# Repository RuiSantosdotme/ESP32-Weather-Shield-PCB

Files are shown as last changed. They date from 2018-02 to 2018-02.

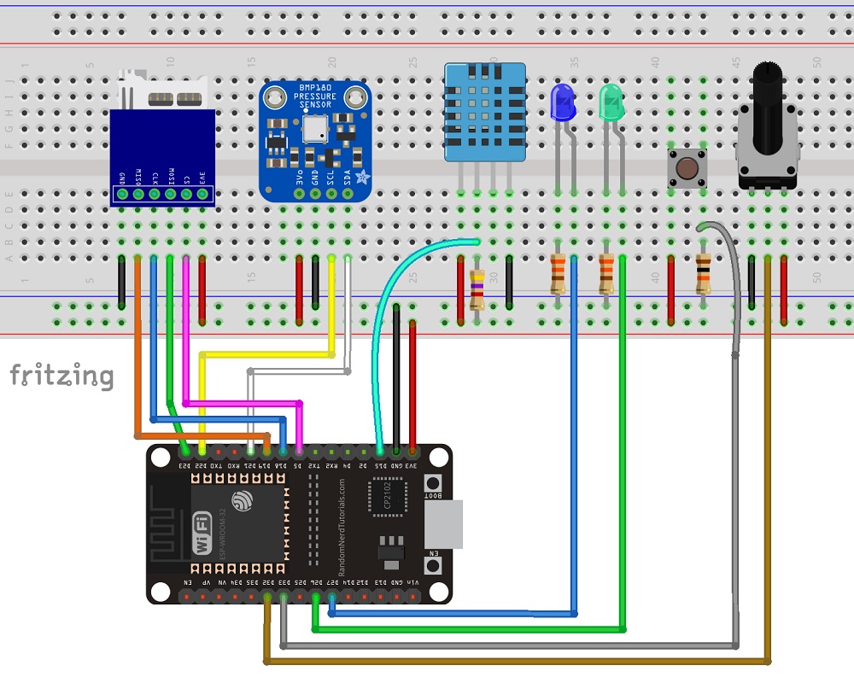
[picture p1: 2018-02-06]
Images/ESP32-shield-breadboard.jpg

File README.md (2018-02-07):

# Build an All-in-One ESP32 Weather Station Shield

In this project I’ll show you how you can build an all-in-one ESP32 weather station shield and display the sensor readings on a web server. The web server displays data from all the sensors and automatically updates the readings every ten seconds, without the need to refresh the web page.

You can watch the video tutorial and demonstration here: https://youtu.be/m5cS21AAhZo

For the complete step-by-step instructions, visit: https://randomnerdtutorials.com/build-an-all-in-one-esp32-weather-station-shield/

How to browse the GitHub repository:
- [Web server code (for Arduino IDE)](https://raw.githubusercontent.com/RuiSantosdotme/ESP32-Weather-Shield-PCB/master/Code/ESP32_Weather_Station_Shield/ESP32_Weather_Station_Shield.ino)
- [HTML page](https://raw.githubusercontent.com/RuiSantosdotme/ESP32-Weather-Shield-PCB/master/Code/index.html)
- [Schematic diagram](https://github.com/RuiSantosdotme/ESP32-Weather-Shield-PCB/tree/master/Images)
- [Gerber files](https://github.com/RuiSantosdotme/ESP32-Weather-Shield-PCB/raw/master/KiCad_PCB_ESP32_Shield/GERBERS/ESP32_Shield_Gerbers.zip)
- [KiCad project to edit the PCB](https://github.com/RuiSantosdotme/ESP32-Weather-Shield-PCB/tree/master/KiCad_PCB_ESP32_Shield)
- [Click here to download all the files](https://github.com/RuiSantosdotme/ESP32-Weather-Shield-PCB/archive/master.zip)

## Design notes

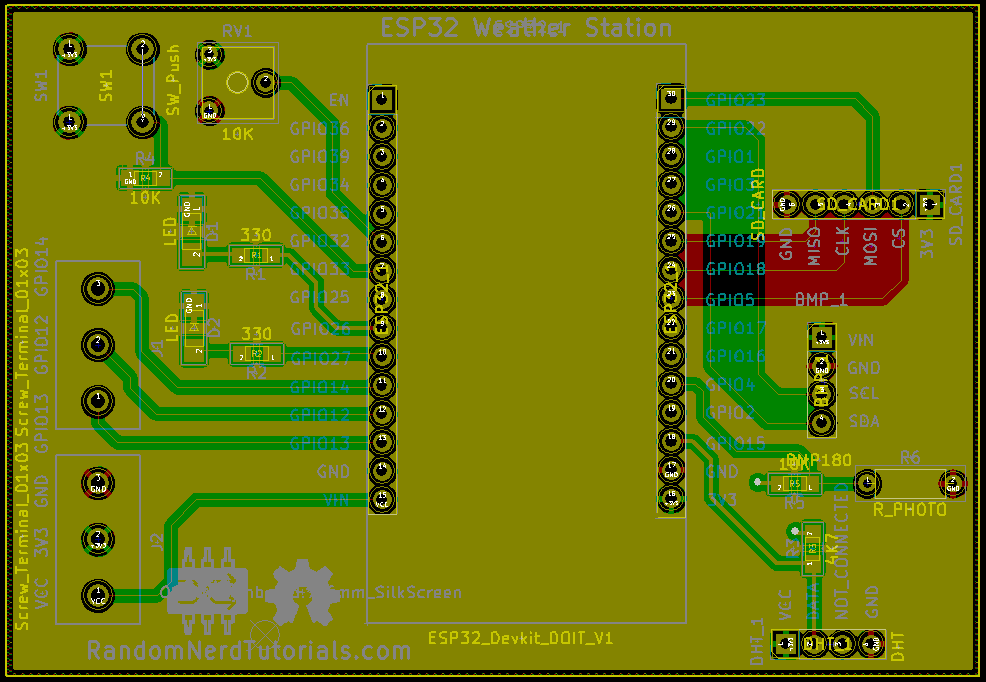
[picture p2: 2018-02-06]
Images/KiCad-PCB-top-view.png

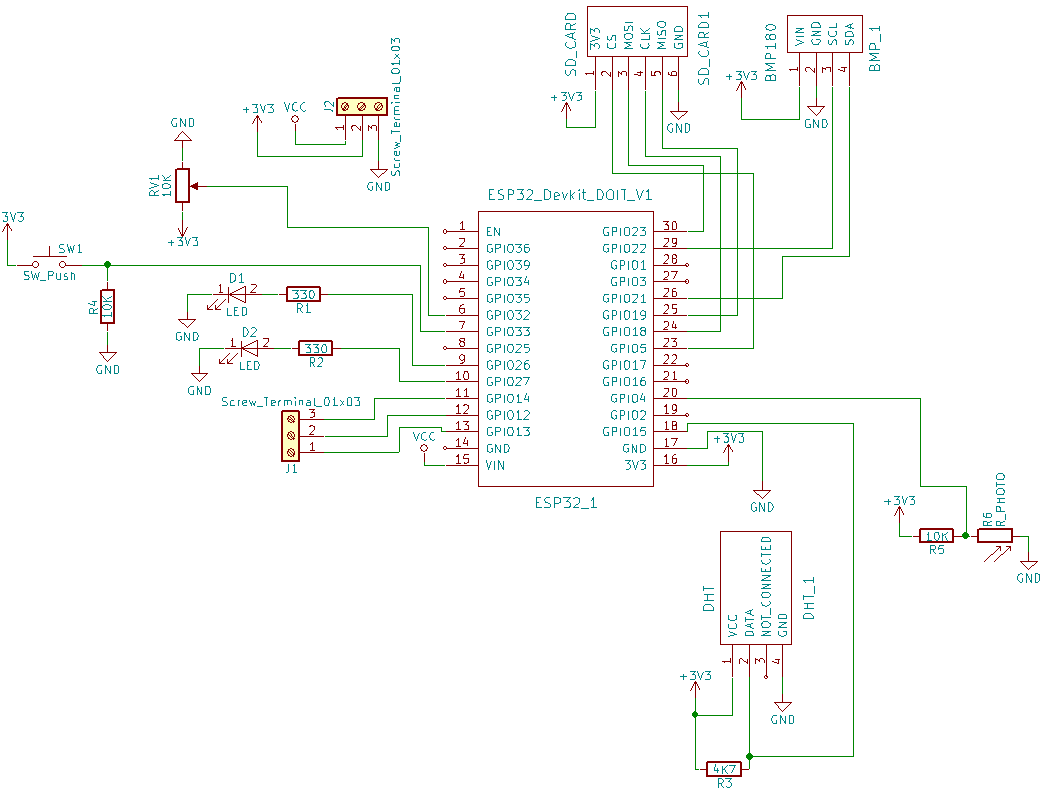
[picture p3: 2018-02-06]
Images/KiCad-circuit.png

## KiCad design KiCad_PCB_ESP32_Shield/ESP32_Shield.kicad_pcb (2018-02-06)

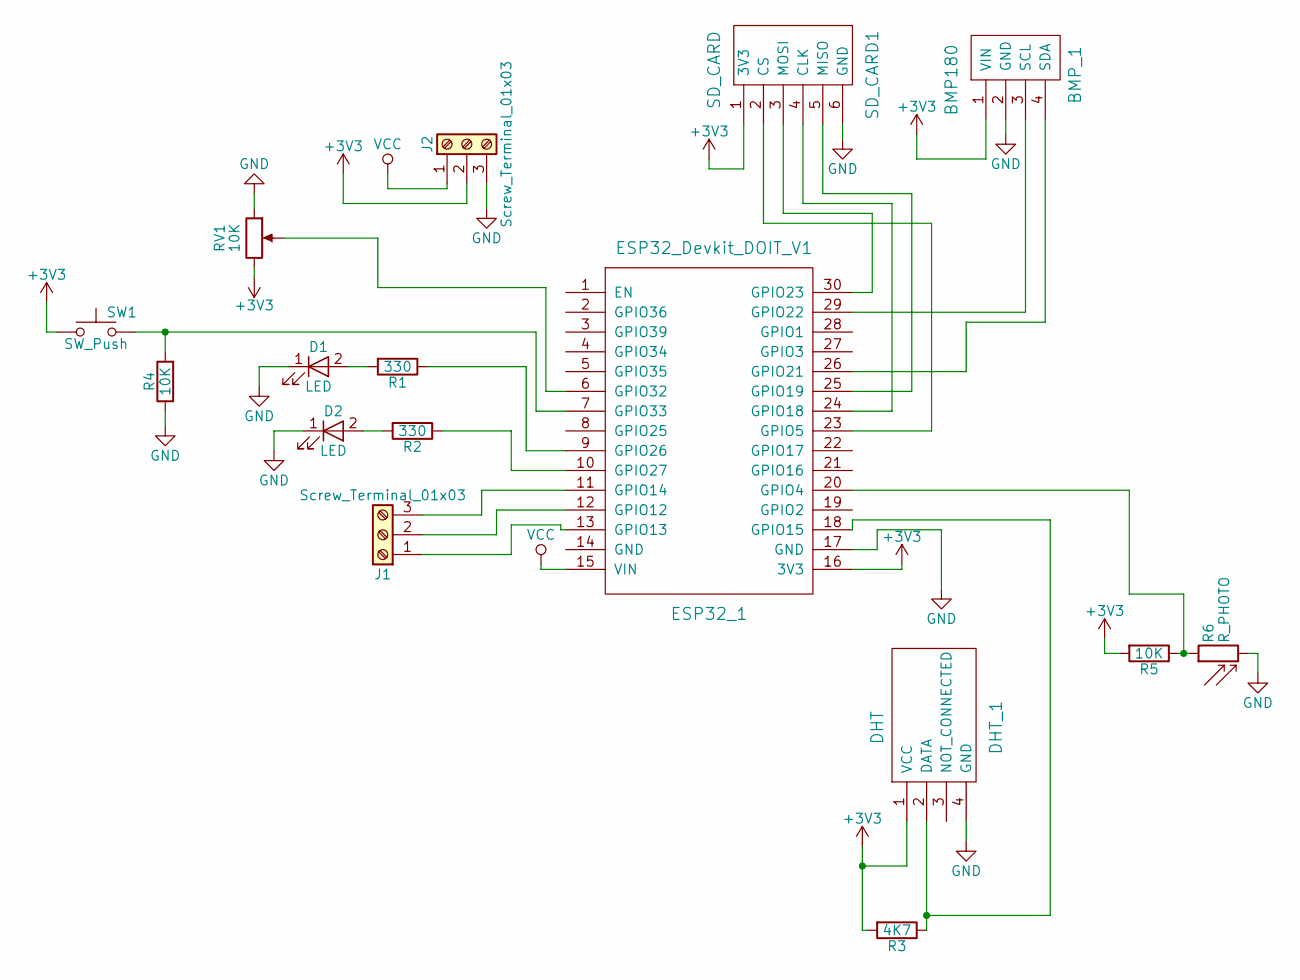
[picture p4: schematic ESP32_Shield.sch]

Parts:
BMP_1: BMP180
D1, D2: LED; LED_1206_HandSoldering
DHT_1: DHT
ESP32_1: ESP32_Devkit_DOIT_V1
J1: Screw_Terminal_01x03; TerminalBlock_5mm_Pins
J2: Screw_Terminal_01x03; TerminalBlock_5mm
R1, R2: 330; R_0805_HandSoldering
R3: 4K7; R_0805_HandSoldering
R4, R5: 10K; R_0805_HandSoldering
R6: R_PHOTO; R_Axial_DIN0207_L6.3mm_D2.5mm_P7.62mm_Horizontal
RV1: 10K; Potentiometer_Trimmer_ACP_CA6v_Horizontal
SD_CARD1: SD_CARD
SW1: SW_Push; SW_PUSH_6mmx6mm

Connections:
+3V3: BMP_1.1 (VIN), DHT_1.1 (VCC), ESP32_1.16 (3V3), J2.2, R3.2, R5.2, RV1.3, SD_CARD1.1 (3V3), SW1.1
GND: BMP_1.2 (GND), D1.1 (K), D2.1 (K), DHT_1.4 (GND), ESP32_1.17 (GND), J2.3, R4.1, R6.2, RV1.1, SD_CARD1.6 (GND)
unnamed: BMP_1.3 (SCL), ESP32_1.29 (GPIO22)
unnamed: BMP_1.4 (SDA), ESP32_1.26 (GPIO21)
unnamed: D1.2 (A), R1.2
unnamed: D2.2 (A), R2.2
unnamed: DHT_1.2 (DATA), ESP32_1.18 (GPIO15), R3.1
unnamed: ESP32_1.6 (GPIO32), RV1.2
unnamed: ESP32_1.7 (GPIO33), R4.2, SW1.2
unnamed: ESP32_1.9 (GPIO26), R1.1
unnamed: ESP32_1.10 (GPIO27), R2.1
unnamed: ESP32_1.11 (GPIO14), J1.3
unnamed: ESP32_1.12 (GPIO12), J1.2
unnamed: ESP32_1.13 (GPIO13), J1.1
unnamed: ESP32_1.20 (GPIO4), R5.1, R6.1
unnamed: ESP32_1.23 (GPIO5), SD_CARD1.2 (CS)
unnamed: ESP32_1.24 (GPIO18), SD_CARD1.4 (CLK)
unnamed: ESP32_1.25 (GPIO19), SD_CARD1.5 (MISO)
unnamed: ESP32_1.30 (GPIO23), SD_CARD1.3 (MOSI)
VCC: ESP32_1.15 (VIN), J2.1

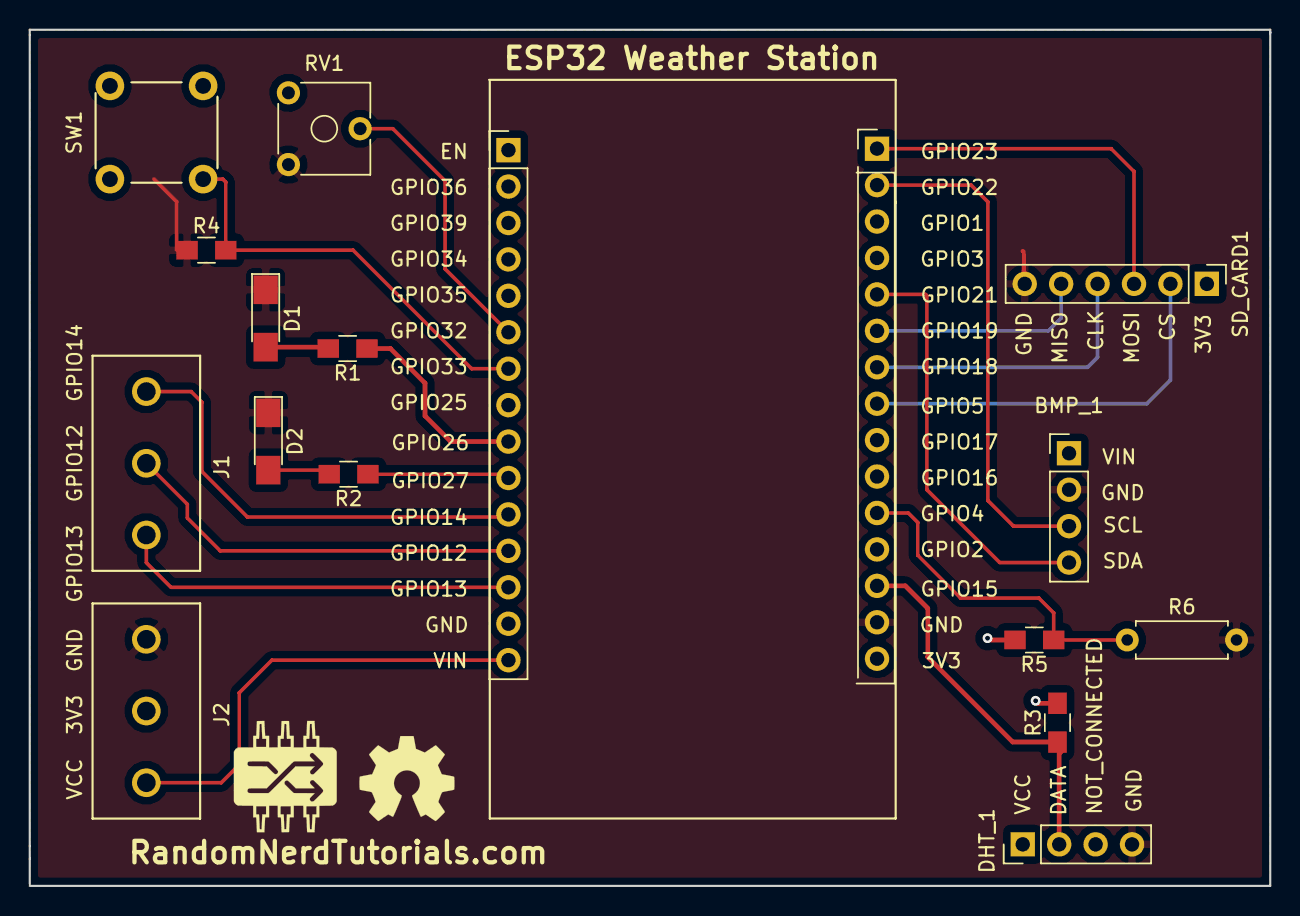
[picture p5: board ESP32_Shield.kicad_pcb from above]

Board: 2 copper layers, 86.5 x 59.7 mm, 16 parts (0 on the bottom side), 20 nets.

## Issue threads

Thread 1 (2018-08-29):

Project Licensing

Alpistinho, 2018-08-29:
Hi Rui,

I was wondering if this project had a license defined.
I wanted to use your schematic library and footprint for the ESP32 in order to create a small breakout board, but I don't know if I can do that without violating your license.

Thanks

RuiSantosdotme, 2018-08-30:
Hello Alpistinho,
You can take this project, modify it and do pretty much anything you want with it (even for commercial purposes). We appreciate if you could mention our work as a resource and give us attribution wherever is possible (a link to https://randomnerdtutorials.com ) .

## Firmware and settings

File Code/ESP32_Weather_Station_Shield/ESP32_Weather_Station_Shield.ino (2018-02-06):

/*
 * Rui Santos 
 * Complete Project Details http://randomnerdtutorials.com
 */

// Load required libraries
#include <WiFi.h>
#include "SD.h"
#include "DHT.h"
#include <Wire.h>
#include <Adafruit_BMP085.h>

// Replace with your network credentials
const char* ssid     = "REPLACE_WITH_YOUR_SSID";
const char* password = "REPLACE_WITH_YOUR_PASSWORD";

// uncomment one of the lines below for whatever DHT sensor type you're using
//#define DHTTYPE DHT11   // DHT 11
//#define DHTTYPE DHT21   // DHT 21 (AM2301)
#define DHTTYPE DHT22   // DHT 22  (AM2302), AM2321

// GPIO the DHT is connected to
const int DHTPin = 15;
//intialize DHT sensor
DHT dht(DHTPin, DHTTYPE);

// create a bmp object
Adafruit_BMP085 bmp;

// Web page file stored on the SD card
File webFile; 

// Set potentiometer GPIO
const int potPin = 32;

// IMPORTANT: At the moment, GPIO 4 doesn't work as an ADC when using the Wi-Fi library
// This is a limitation of this shield, but you can use another GPIO to get the LDR readings
const int LDRPin = 4;

// variables to store temperature and humidity
float tempC;
float tempF;
float humi;

// Variable to store the HTTP request
String header;

// Set web server port number to 80
WiFiServer server(80);

void setup(){    
  // initialize serial port
  Serial.begin(115200); 

  // initialize DHT sensor
  dht.begin();

  // initialize BMP180 sensor
  if (!bmp.begin()){
    Serial.println("Could not find BMP180 or BMP085 sensor");
    while (1) {}
  }

  // initialize SD card
  if(!SD.begin()){
      Serial.println("Card Mount Failed");
      return;
  }
  uint8_t cardType = SD.cardType();
  if(cardType == CARD_NONE){
      Serial.println("No SD card attached");
      return;
  }
  // initialize SD card
  Serial.println("Initializing SD card...");
  if (!SD.begin()) {
      Serial.println("ERROR - SD card initialization failed!");
      return;    // init failed
  }

  // Connect to Wi-Fi network with SSID and password
  Serial.print("Connecting to ");
  Serial.println(ssid);
  WiFi.begin(ssid, password);

  while (WiFi.status() != WL_CONNECTED) {
    delay(500);
    Serial.print(".");
  }

  // Print local IP address and start web server
  Serial.println("");
  Serial.println("WiFi connected.");
  Serial.println("IP address: ");
  Serial.println(WiFi.localIP());
  server.begin();
}

void loop(){
  WiFiClient client = server.available();   // Listen for incoming clients

  if (client) {  // if new client connects
    boolean currentLineIsBlank = true;
    while (client.connected()) {
      if (client.available()) {   // client data available to read
        char c = client.read(); // read 1 byte (character) from client
        header += c;
        // if the current line is blank, you got two newline characters in a row.
        // that's the end of the client HTTP request, so send a response:
        if (c == '\n' && currentLineIsBlank) {
          // send a standard http response header
          client.println("HTTP/1.1 200 OK");
          // Send XML file or Web page
          // If client already on the web page, browser requests with AJAX the latest
          // sensor readings (ESP32 sends the XML file)
          if (header.indexOf("update_readings") >= 0) {
            // send rest of HTTP header
            client.println("Content-Type: text/xml");
            client.println("Connection: keep-alive");
            client.println();
            // Send XML file with sensor readings
            sendXMLFile(client);
          }
          // When the client connects for the first time, send it the index.html file
          // stored in the microSD card
          else {  
            // send rest of HTTP header
            client.println("Content-Type: text/html");
            client.println("Connection: keep-alive");
            client.println();
            // send web page stored in microSD card
            webFile = SD.open("/index.html");
            if (webFile) {
              while(webFile.available()) {
                // send web page to client
                client.write(webFile.read()); 
              }
              webFile.close();
            }
          }
          break;
        }
        // every line of text received from the client ends with \r\n
        if (c == '\n') {
          // last character on line of received text
          // starting new line with next character read
          currentLineIsBlank = true;
        } 
        else if (c != '\r') {
          // a text character was received from client
          currentLineIsBlank = false;
        }
        } // end if (client.available())
    } // end while (client.connected())
    // Clear the header variable
    header = "";
    // Close the connection
    client.stop();
    Serial.println("Client disconnected.");
  } // end if (client)
}

// Send XML file with the latest sensor readings
void sendXMLFile(WiFiClient cl){
  // Read DHT sensor and update variables
  readDHT();

  // Prepare XML file
  cl.print("<?xml version = \"1.0\" ?>");
  cl.print("<inputs>");

  cl.print("<reading>");
  cl.print(tempC);
  cl.println("</reading>");
  
  cl.print("<reading>");
  cl.print(tempF);
  cl.println("</reading>");
  
  cl.print("<reading>");
  cl.print(humi);
  cl.println("</reading>");
  
  float currentTemperatureC = bmp.readTemperature();
  cl.print("<reading>");
  cl.print(currentTemperatureC);
  cl.println("</reading>");
  float currentTemperatureF = (9.0/5.0)*currentTemperatureC+32.0;
  cl.print("<reading>");
  cl.print(currentTemperatureF);
  cl.println("</reading>");
  
  cl.print("<reading>");
  cl.print(bmp.readPressure());
  cl.println("</reading>");
  
  cl.print("<reading>");
  cl.print(analogRead(potPin));
  cl.println("</reading>");

  // IMPORTANT: Read the note about GPIO 4 at the pin assignment 
  cl.print("<reading>");
  cl.print(analogRead(LDRPin));
  cl.println("</reading>");
  
  cl.print("</inputs>");
}

void readDHT(){
  // Sensor readings may also be up to 2 seconds 'old' (its a very slow sensor)
  humi = dht.readHumidity();
  // Read temperature as Celsius (the default)
  tempC = dht.readTemperature();
  // Read temperature as Fahrenheit (isFahrenheit = true)
  tempF = dht.readTemperature(true);

  // Check if any reads failed and exit early (to try again).
  if (isnan(humi) || isnan(tempC) || isnan(tempF)) {
    Serial.println("Failed to read from DHT sensor!");
    return;
  }

  /*Serial.print("Humidity: ");
  Serial.print(humi);
  Serial.print(" %\t Temperature: ");
  Serial.print(tempC);
  Serial.print(" *C ");
  Serial.print(tempF);
  Serial.println(" *F");*/
}

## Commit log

2018-02-06 KiCad Project
    [ESP32_Shield-B.Cu.gbr, ESP32_Shield-B.Mask.gbr, ESP32_Shield-B.SilkS.gbr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]
2018-02-06 Project circuit and Images
2018-02-06 Arduino Code for ESP32 and HTML page
